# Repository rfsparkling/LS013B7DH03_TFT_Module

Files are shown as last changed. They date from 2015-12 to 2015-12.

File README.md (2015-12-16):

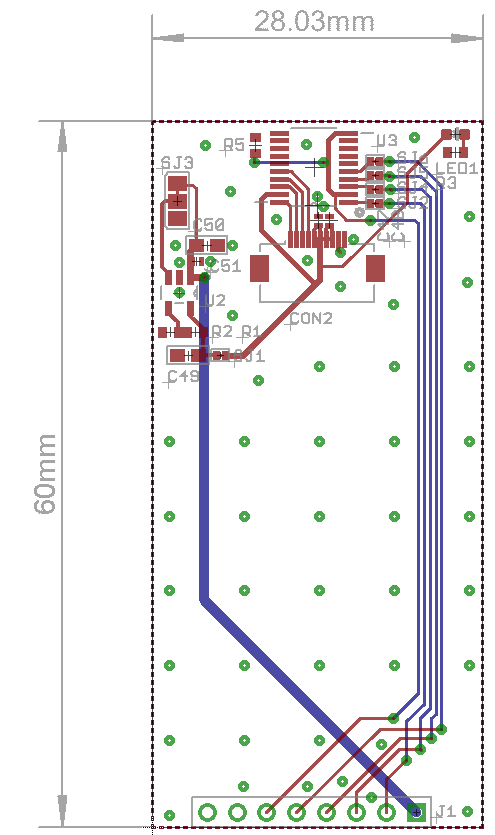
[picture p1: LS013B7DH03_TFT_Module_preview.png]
layout preview


1.28-inch (diagonal) Memory LCD with Voltage Level Shifter and LDO, in Eagle CAD

Already assambled PCB, validated and it works.

I have assambled PCBs to sell, please contact me about the details!

http://www.sharpmemorylcd.com/1-28-inch-memory-lcd.html

"Sharp’s 1.28-inch (diagonal) Memory LCD is ideal for digital wristwatches and other small-screen applications, with a 3V input voltage that makes it compatible for operation with a single cell Lithium ion battery. Its high-resolution, dot matrix display delivers smooth graphics and the flexibility to showcase rich custom content.

Overview 
- 1.28 inch 128 x 128 monochrome HR-TFT transflective panel 
- Transmissive mode is available by implemention with backlight. (Transmition ratio is around 0.2%) 
- 128x 128 dot stripe arrangement 
- Display control with serial data signal communication 
- Arbitrary gate line is selectable to data update   
- Internal 1bit memory within the panel for data memory 
- Thin, light and compact module with monolithic technology 
- Super low power consumption TFT panel 
- With FPC (Applicable connector:    Refer to recommended connector on page 21.)  "

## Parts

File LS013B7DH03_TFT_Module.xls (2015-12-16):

Part | Value | Device | Package | Description | ALTDISTRI_NEWARK | DISTRI | DISTRINR | MURATA | PACKAGE | PARTNR | SUPPLIER | VENDOR
C47 | 100nF | CAP_GRM15 | CAPC1005X60N | Murata | GRM15 | series | 402 | size | capacitor | GRM15 | series
C48 | 100nF | CAP_GRM15 | CAPC1005X60N | Murata | GRM15 | series | 402 | size | capacitor | GRM15 | series
C49 | 1uF | CAP-SMD0603 | 603
C50 | 1uF | CAP-SMD0603 | 603
C51 | 220nF | CAP_GRM15 | CAPC1005X60N | Murata | GRM15 | series | 402 | size | capacitor | GRM15 | series
CON2 | MOLEX_52892-1033 | MOLEX_52892-1033_FPC | MOLEX_52892-1095 | MOLEX | - | 52892-1033 | - | SOCKET, | FFC/FPC, | ZIF, | 0.50MM, | 10P | Farnell | 2361354 | 52892-1033
J1 | N.F. | N.F. | N.F.
LED1 | LED0603 | LED-0603 | LEDs
R1 | 52.3k | R-US_R0402 | R0402 | RESISTOR, | American | symbol
R2 | 30.1k | R-US_R0402 | R0402 | RESISTOR, | American | symbol
R3 | 470 | R-US_R0402 | R0402 | RESISTOR, | American | symbol
R5 | 100k | R-US_R0402 | R0402 | RESISTOR, | American | symbol
U2 | TPS73601DBVR | TPS73601DBVR | SOT95P280X145-5N | Cap-Free, | NMOS, | 400mA | Low-Dropout | Regulator | with | Reverse | Current | Protection | 87H2971 | Farnell | 1576489 | SOT-23-5 | TPS73601DBVR | Texas | Instruments
U3 | TXS0108EPWR | TXB0108PWR | SOP65P640X120-20N | 8-BIT | BIDIRECTIONAL | VOLTAGE-LEVEL | TRANSLATOR | TSSOP-20 | Texas | Instruments

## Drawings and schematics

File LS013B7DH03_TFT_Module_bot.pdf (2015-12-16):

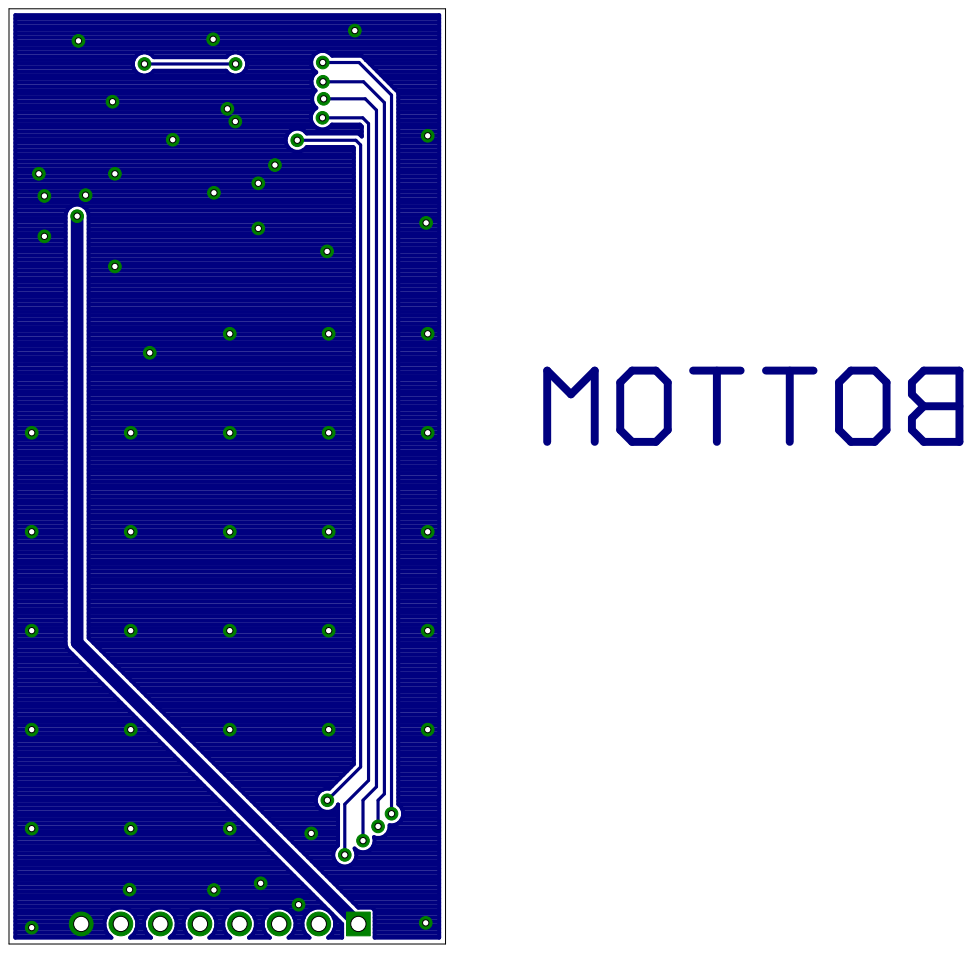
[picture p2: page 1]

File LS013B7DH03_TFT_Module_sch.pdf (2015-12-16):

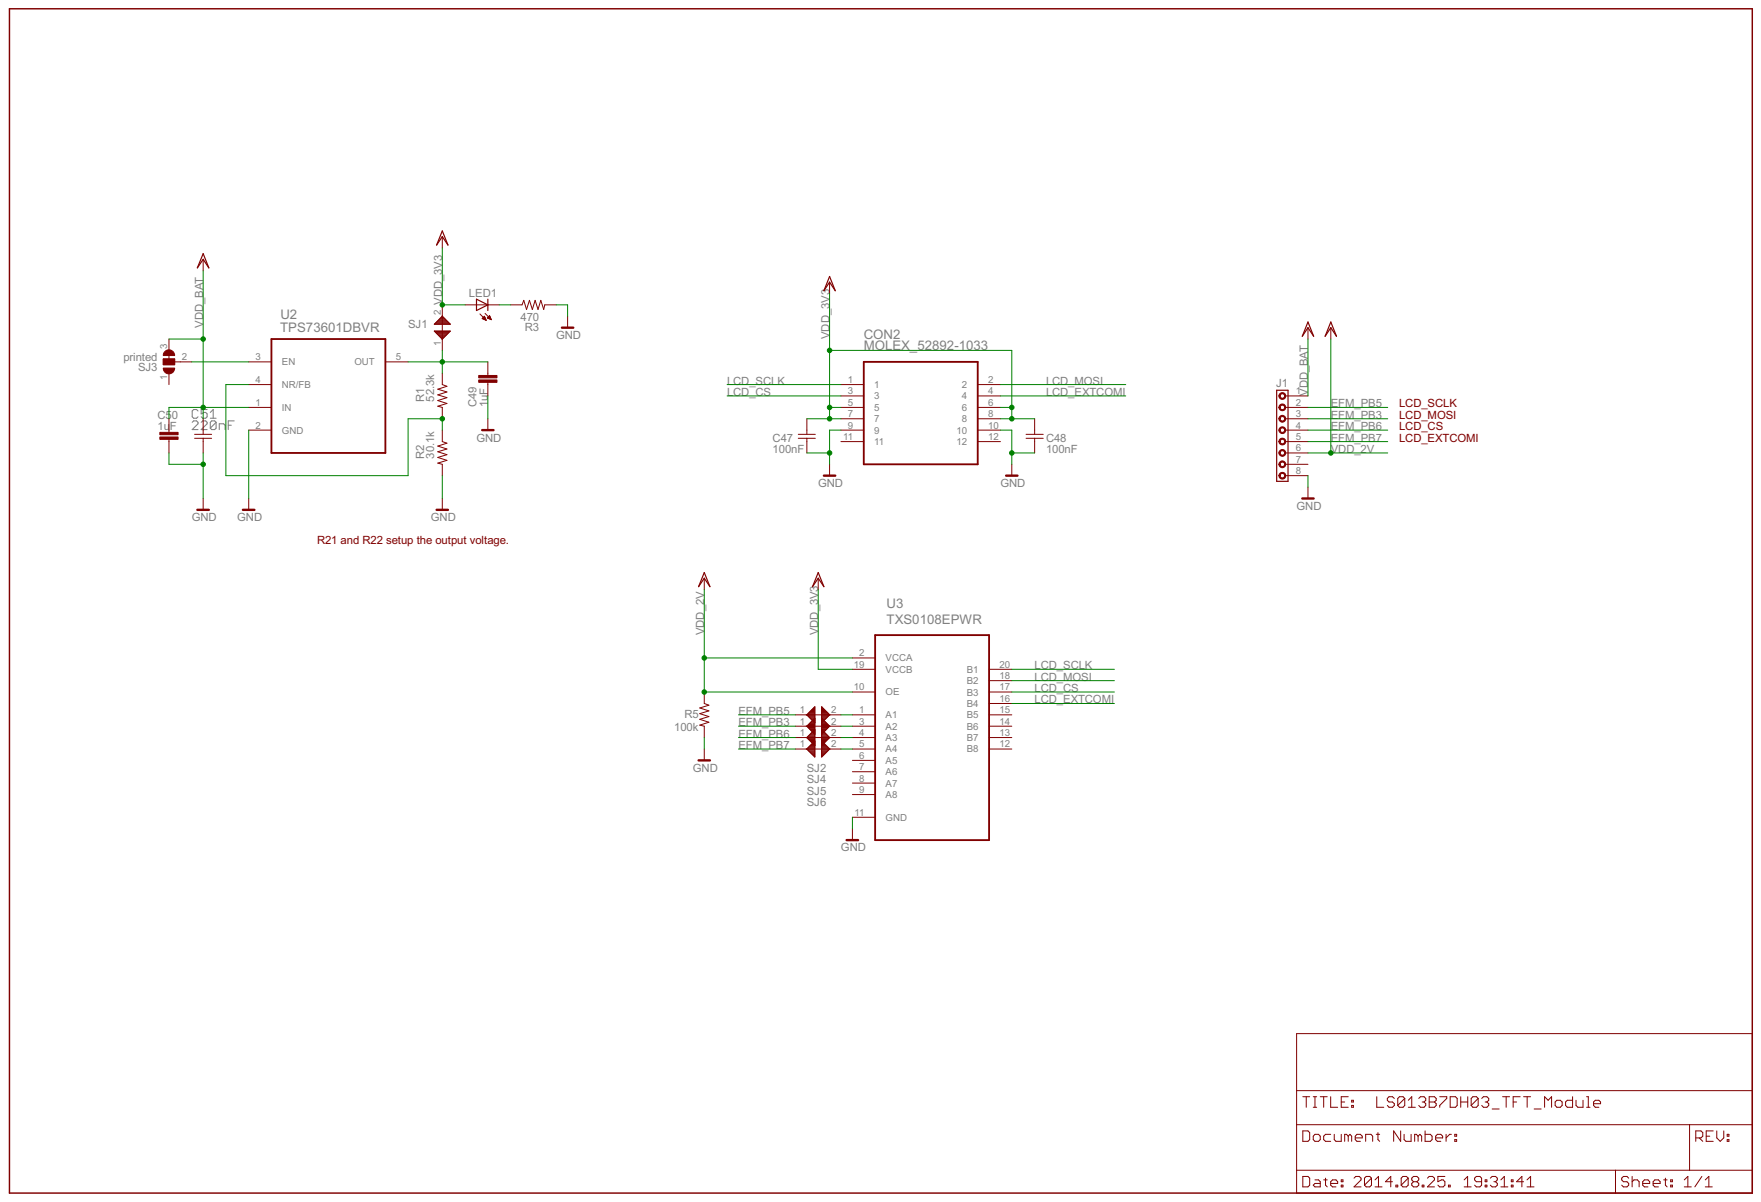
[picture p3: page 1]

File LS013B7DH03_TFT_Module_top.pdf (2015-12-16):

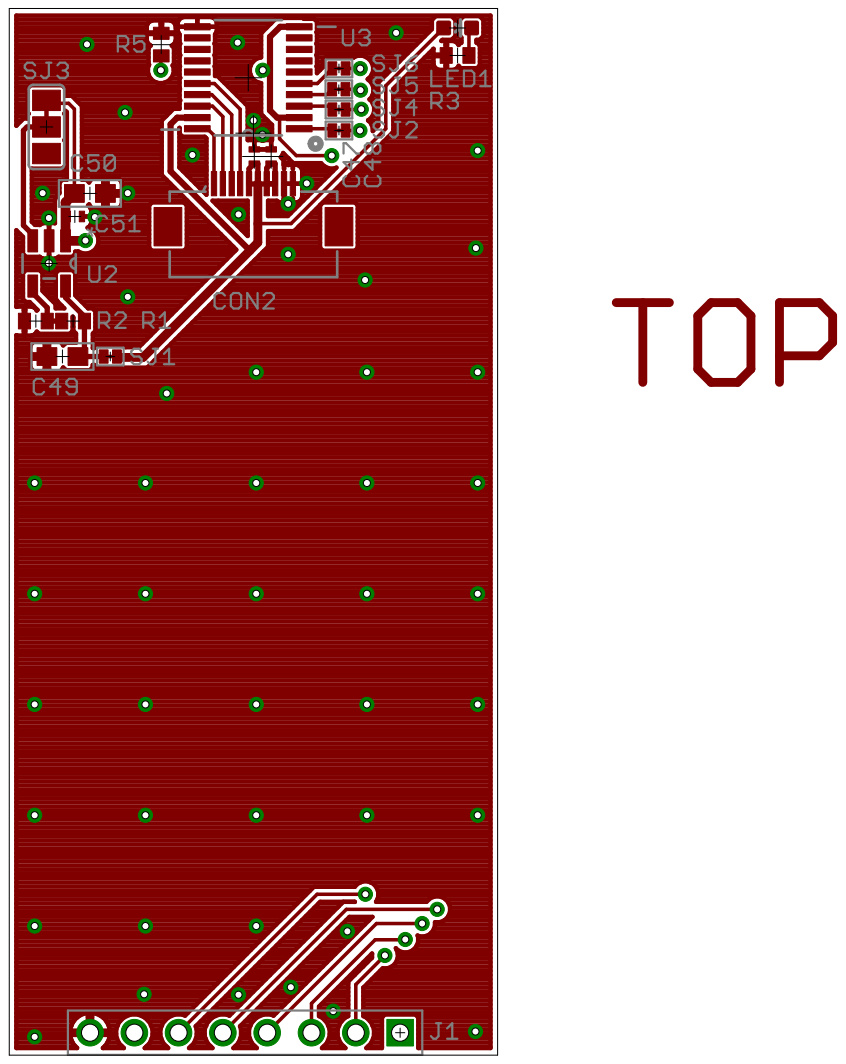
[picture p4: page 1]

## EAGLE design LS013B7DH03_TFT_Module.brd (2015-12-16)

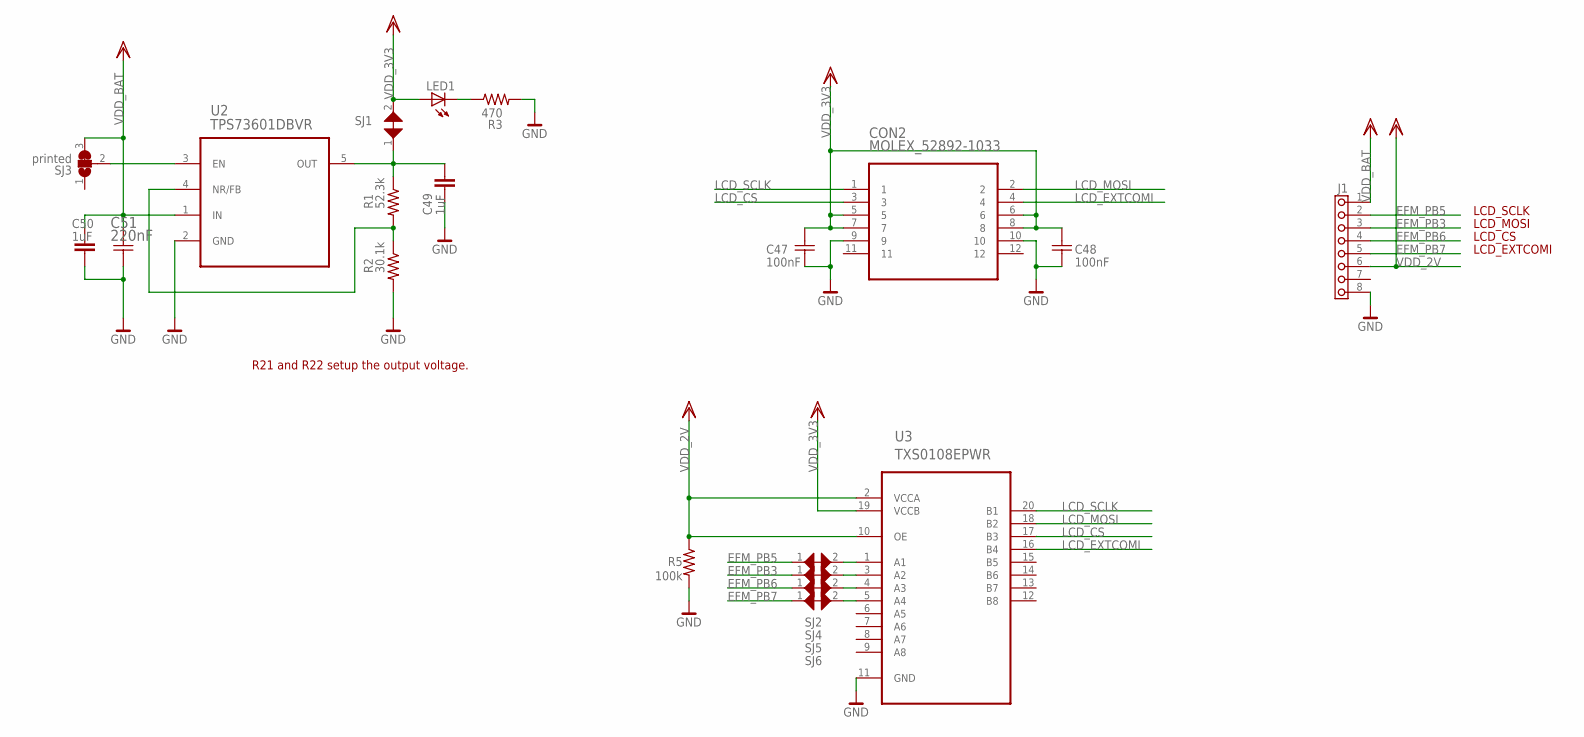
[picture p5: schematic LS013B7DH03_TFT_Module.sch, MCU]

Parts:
C47, C48: 100nF; CAPC1005X60N
C49, C50: 1uF; 0603
C51: 220nF; CAPC1005X60N
CON2: MOLEX_52892-1033; MOLEX_52892-1095
J1: PIN8S
LED1: LED0603; LED-0603
R1: 52.3k; R0402
R2: 30.1k; R0402
R3: 470; R0402
R5: 100k; R0402
SJ1, SJ2, SJ4, SJ5, SJ6: printed; JUMPER_SMD_MICRO_SHORT
SJ3: printed; JUMPER_SMD_SJ2A
U2: TPS73601DBVR; SOT95P280X145-5N
U3: TXS0108EPWR; SOP65P640X120-20N

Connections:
EFM_PB3: J1.3, SJ4.1
EFM_PB5: J1.2, SJ2.1
EFM_PB6: J1.4, SJ5.1
EFM_PB7: J1.5, SJ6.1
GND: C47.2 (C2), C48.2 (C2), C49.1, C50.1, C51.2 (C2), CON2.9, CON2.10, J1.8, R2.2, R3.2, R5.2, U2.2 (GND), U3.11 (GND)
LCD_CS: CON2.3, U3.17 (B3)
LCD_EXTCOMI: CON2.4, U3.16 (B4)
LCD_MOSI: CON2.2, U3.18 (B2)
LCD_SCLK: CON2.1, U3.20 (B1)
unnamed: LED1.C, R3.1
unnamed: SJ2.2, U3.1 (A1)
unnamed: SJ4.2, U3.3 (A2)
unnamed: SJ5.2, U3.4 (A3)
unnamed: SJ6.2, U3.5 (A4)
unnamed: C49.2, R1.1, SJ1.1, U2.5 (OUT)
unnamed: R1.2, R2.1, U2.4 (NR/FB)
unnamed: SJ3.2, U2.3 (EN)
VDD_2V: J1.6, R5.1, U3.2 (VCCA), U3.10 (OE)
VDD_3V3: C47.1 (C1), C48.1 (C1), CON2.5, CON2.6, CON2.7, CON2.8, LED1.A, SJ1.2, U3.19 (VCCB)
VDD_BAT: C50.2, C51.1 (C1), J1.1, SJ3.3, U2.1 (IN)

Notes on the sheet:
R21 and R22 setup the output voltage.
LCD_SCLK
LCD_MOSI
LCD_CS
LCD_EXTCOMI

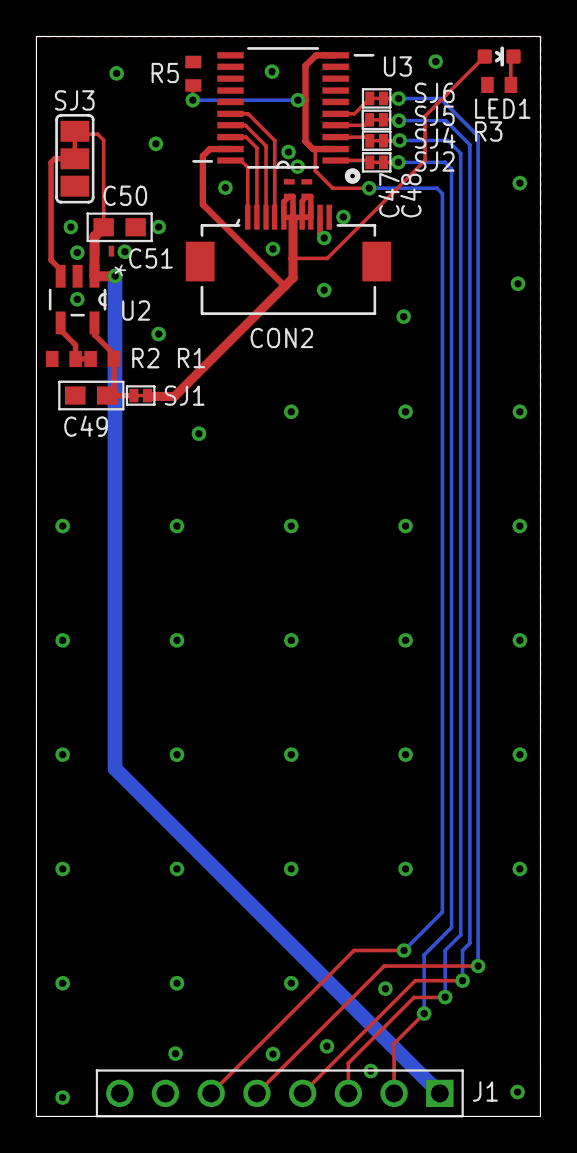
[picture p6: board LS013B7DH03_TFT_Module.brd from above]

Board: 2 copper layers, 28.0 x 60.0 mm, 20 parts (0 on the bottom side), 20 nets.
